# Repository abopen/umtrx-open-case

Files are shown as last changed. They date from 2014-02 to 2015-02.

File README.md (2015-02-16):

# UmTRX Open Case

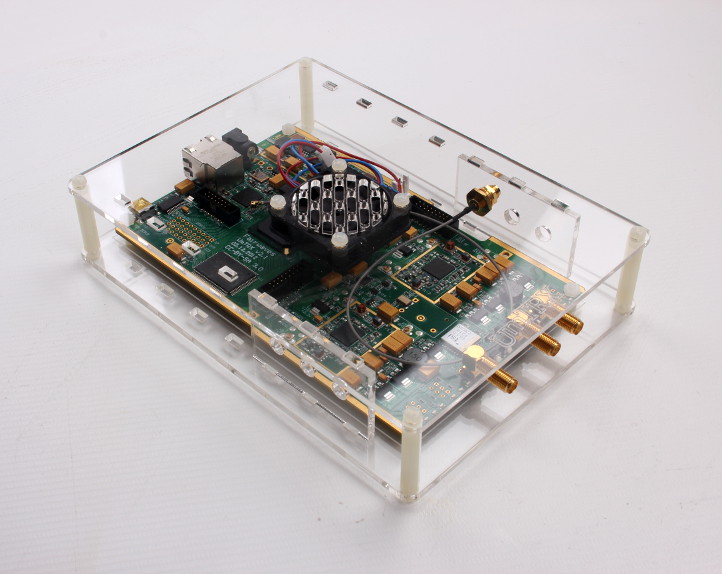
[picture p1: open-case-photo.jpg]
UmTRX open case


A simple open case for the [UmTRX v2.1](http://umtrx.org/) SDR transceiver.

The design is available in the following formats:

* Corel Draw (source)
* SVG
* PNG
* PDF
* DXF

Note design was revised and modified in Illustrator CS5 using PDF as source.

## Material and cutting

Designed to be laser cut from 3mm clear colourless acrylic.

## Cooling

An [EBM PAPST 405F](http://www.ebmpapst.com/en/products/compact-fans/axial-compact-fans/axial_compact_fans_detail.php?pID=53727) was used, but other 5vdc fans of similar proportions may be suitable. Since the UmTRX fan power output is 6v, a 100 ohm resistor was inserted in-line to drop the voltage.

It may be prudent to add a heatsink to the FPGA also.

## Fittings

| Qty | Item |
| --- | --- |
|  12 | M3 12mm nylon screw |
|  4  | M3 30mm nylon hex threaded spacer |
|  4  | 3.2mm ID x 3mm circular nylon spacer|
|  4  | M3 16mm nylon screw |
|  4  | M3 nylon nut |

## Licence

Copyright 2014 [AB Open Ltd](http://abopen.com).

<br />This work is licensed under a <a rel="license" href="http://creativecommons.org/licenses/by/4.0/">Creative Commons Attribution 4.0 International License</a>.

## Thanks

With thanks to [Oomlout](http://oomlout.co.uk/) for their help with design and prototyping.

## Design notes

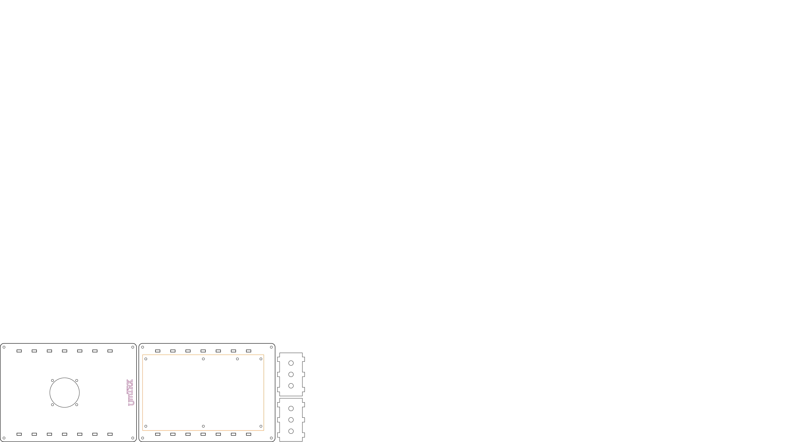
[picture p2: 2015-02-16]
UmTRX.png

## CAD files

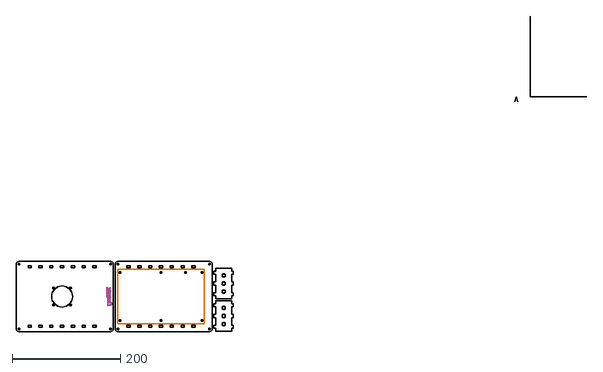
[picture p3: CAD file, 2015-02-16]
UmTRX.dxf
1055.9 x 583.3

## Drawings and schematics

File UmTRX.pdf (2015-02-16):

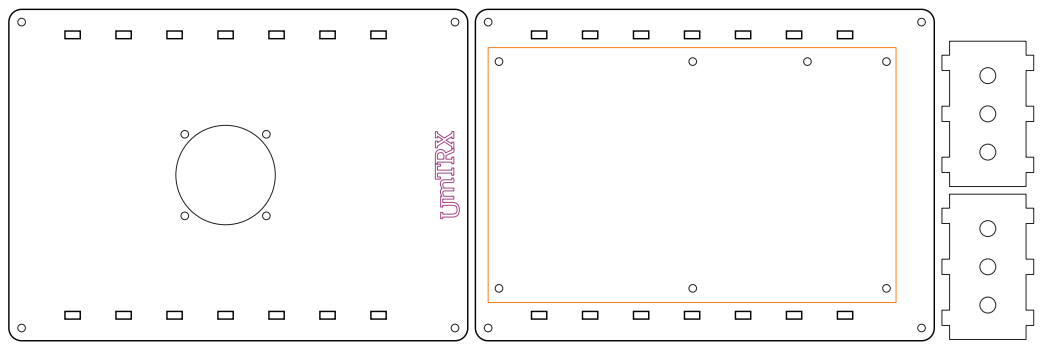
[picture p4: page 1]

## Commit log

2015-02-16 Modified design files to remove grille from fan aperture. Reomved cdr file as no access to Corel Draw - used Adobe Illustrator instead
2015-02-16 Removed grille from fan aperture.
    [UmTRX.dxf]
